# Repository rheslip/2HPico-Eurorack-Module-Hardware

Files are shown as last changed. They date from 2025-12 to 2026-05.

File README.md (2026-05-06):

# 2HPico-Eurorack-Module-Hardware
2HP and 4HP Eurorack modules based on Raspberry Pi RP2350 Pico 2

December 2025 - added Version 1.0 2HPico KiCad design files, BOM, Gerbers for main board and panel board and 3D printable panel.

Jan 28/2025 - added Version 1.0 2HPico DSP PCB design files and FR4 front panel design files and gerbers. 

Feb 16/2026 - JLCPCB assembly files are now verifed. Minor BOM changes to 2HPico DSP as a result of further testing.

April 13/2026 - added 4HPico DSP PCB files. PCB fabbed, tested and working with 1 jumper. 

May 6/2026 - updated 4HPico DSP PCB to V1.1 which corrects missing GND plane connection from middle to bottom of PCB. I have no plans to order these because V 1.0 is fine for me. Changes are minimal so not much risk in ordering V1.1.
Added .stl file for 3D printed panel. No plans to do a PCB panel at this point - I'm happy with the 3D printed panel.

2HPico, 2HPico DSP and 4HPico are complimentary designs intended for different uses:

The 2HPico has 1 or 2 CV inputs and 1 or 2 CV outputs depending on how its jumpered - see notes below. Its dual DAC CV output(s) can also be used for audio generated by the RP2350 processor. 2HPico can be used to process triggers, gates and CV inputs and can generate CV or audio out - its well suited for sequencers, LFOs,  oscillators etc.

2HPico DSP has an audio ADC and DAC to enable signal processing for audio effects like delays, reverbs, chorus etc. 

2HPico and 2HPico DSP use the same front panel and control panel PCBs. 

4HPico is basically the 2HPico DSP with stereo audio in and out and two dedicated CV inputs. Encoder with a 64x32 OLED display instead of pots for setting parameters. This is a single PCB design which requires a 3D printed panel or PCB panel.

See the repository https://github.com/rheslip/2HPico-Sketches for Pico Arduino sketches to run on the 2HPico.

See the repository https://github.com/rheslip/2HPico-DSP-Sketches for Pico Arduino sketches to run on the 2HPico DSP.

See the repository https://github.com/rheslip/4HPico-DSP-Sketches for Pico Arduino sketches to run on the 4HPico DSP.

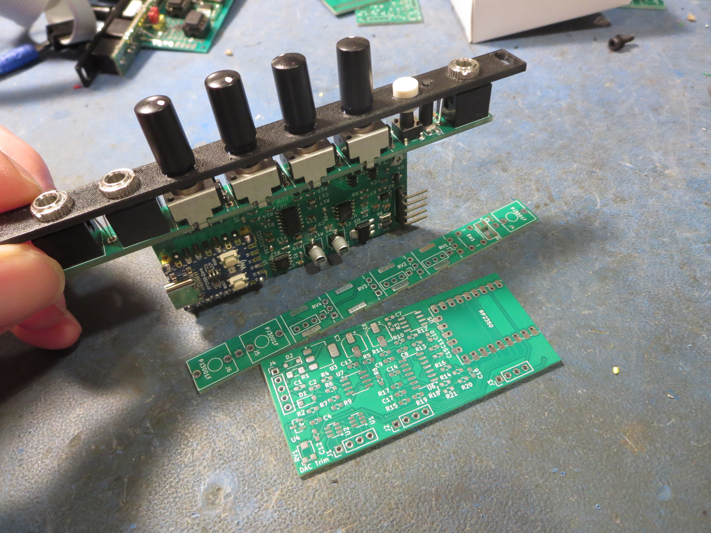
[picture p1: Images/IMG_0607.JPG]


***General notes on the designs***

Waveshare (and others) make small form factor RP2040 and RP2350 boards which make stuffing one into 2HP possible. The RP2350 has much better performance but for simple things like sequencers, ADSR, LFO etc the RP2040 should work OK. Core 0 runs the main processing loop for the UI and control,
core 1 runs the DSP and sends samples to the I2S driver. The code has an option for monitoring the performance of core 1 with a scope. If enabled you will see a pulse on GPIO 8 that indicates how much time core 1 is spending processing samples. If its high more than 100% of the time you will get audio dropouts - time to overclock or optimize your code some more!

The PT8211 16 bit stereo R2R DAC used on the 2HPico is very inexpensive and has proven so far to be quite accurate and consistent from one chip to another (provided they aren't defective - see caveats below). It has no internal antialiasing filters but it works down to DC so can be used as a CV out as well. U6 is a DC coupled antialiasing filter and it also amplifies the DAC output to +-5V eurorack levels.

The 2HPico DSP uses a PCM1808 24 bit stereo audio ADC and a PCM5102A 24 bit stereo audio DAC. The top panel jack is connected to both channels of the PCM1808 and one of the RP2350 ADCs. There is a "DC Input" jumper on the back of the board which shorts the input blocking cap so the top jack can be used for CV input. It adds an approximately 1.6V offset to the input signal so could cause high level audio inputs to clip. Its is recommended to leave the blocking cap in the circuit for audio processing applications.
As with the 2HPico, if the "DAC" solder jumper is shorted audio is sent to both of the lower front panel jacks. Both the PCM1808 and PCM5102A have internal antialiasing filters. Note that the 2HPico DSP can not generate CV outputs because the PCM5102A DAC must be AC coupled.

2HPico DSP build is pretty much the same as the 2HPico but you will be populating a couple of different parts - see the BOM.

***Panel PCB Build notes***

Solder the .1u cap and the RGB LED. Note pin 1 location is NOT the lead with the 45 cut on it - check the picture in the BOM. Hopefully you bought the right pinout! Note these are 5V parts but I haven't had any issues running them at 3.3v - and they are still way too bright!

Solder the jacks - note that the two bottom ones have the same GND via to save real estate

Solder the button. Glue the button cap on with a dab of superglue.

Solder the pots. You can clip the brackets near the bend to make soldering a bit easier but its not required. Make sure they are lined up vertically and horizontally before you solder the brackets to the pads. A Panavise is handy for this step.

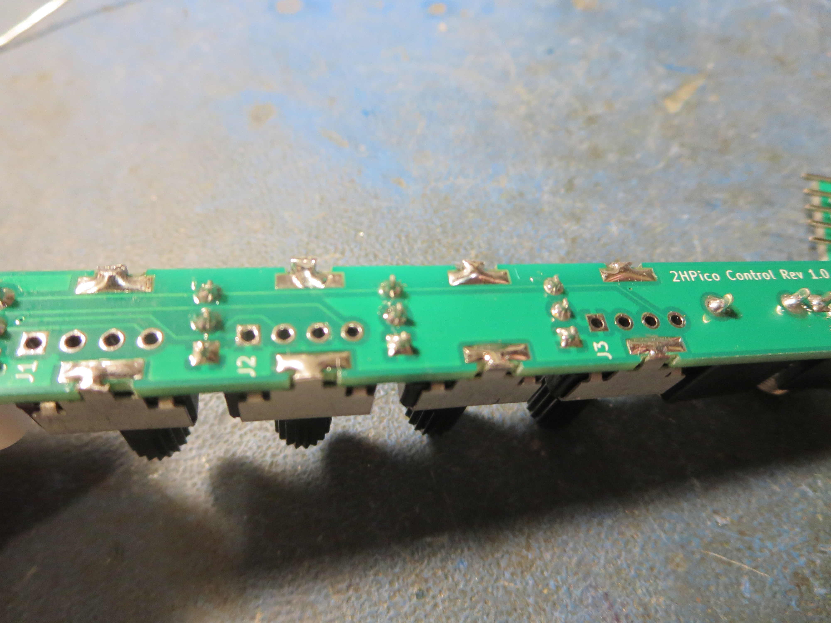
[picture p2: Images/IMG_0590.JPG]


***Main PCB Build Notes***

Solder all the 0603 Rs and Cs first

Solder diodes, R1, U3 regulator, U4 voltage reference and power connector J4. Hook it up to power and check that the 5V, -12V, +12V and -10v reference voltages are OK

Solder in all the chips, the larger caps and the trimpot RV1 (2HPico only).

The Waveshare RP2350 board cannot solder directly to the main PCB because it has components on the bottom side and must stand off a bit. You can solder .1" headers to it and solder the headers to the main PCB or solder .1" header pins in the corners and make the rest of the connections with short wires.

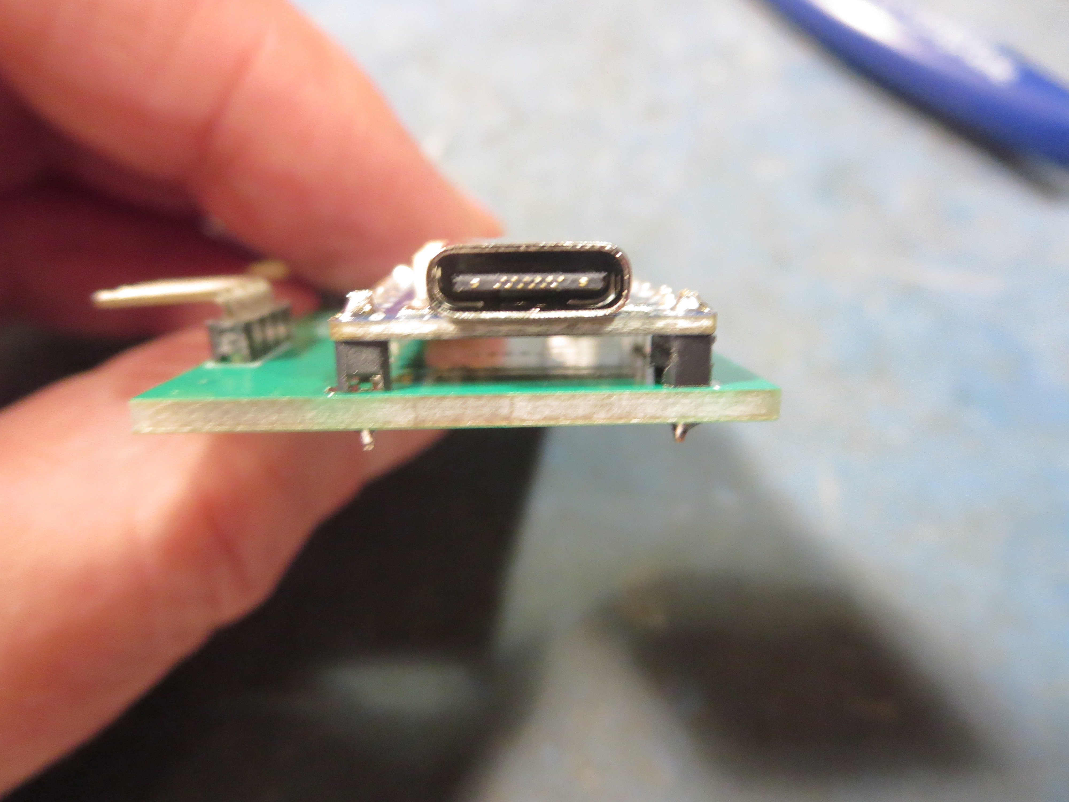
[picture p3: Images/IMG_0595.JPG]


Power up the PCB again and check that the 5V and 3.3V rails are OK.

Solder right angle connectors J1, J2 and J3. The shorter pins solder to the main PCB as shown.

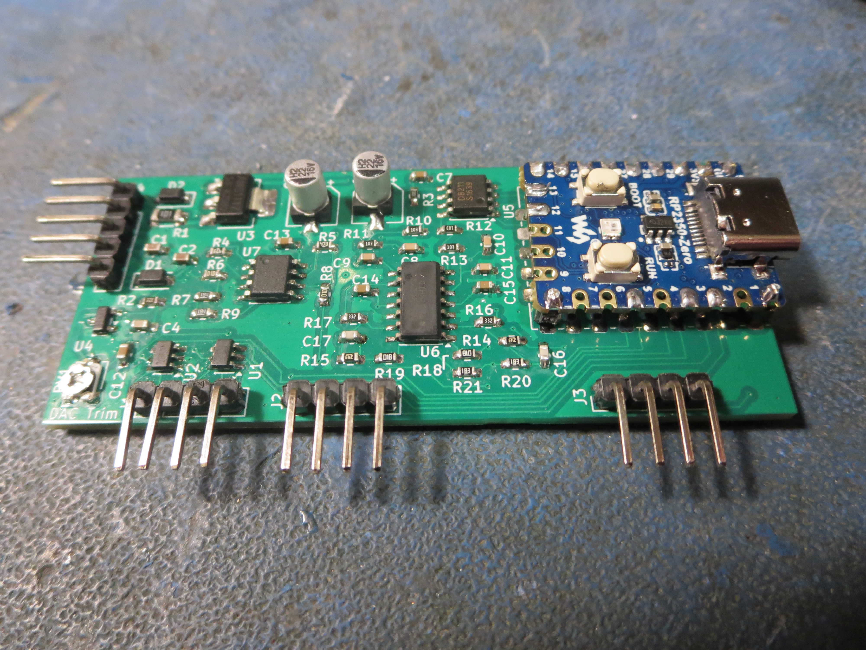
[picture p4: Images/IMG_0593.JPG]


Plug the long end of the right angle connectors into the panel PCB and solder.

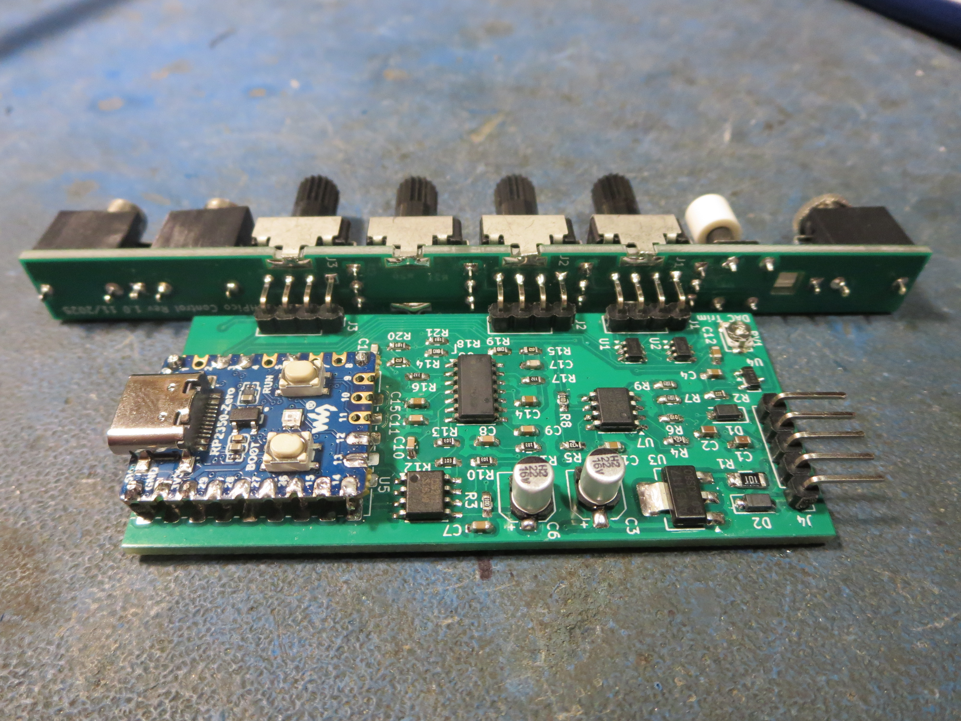
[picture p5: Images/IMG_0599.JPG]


Clip the pins on the bottom side of the main PCB so they don't interfere with adjacent modules - a 2HP module is supposed to be only 10.16mm wide.

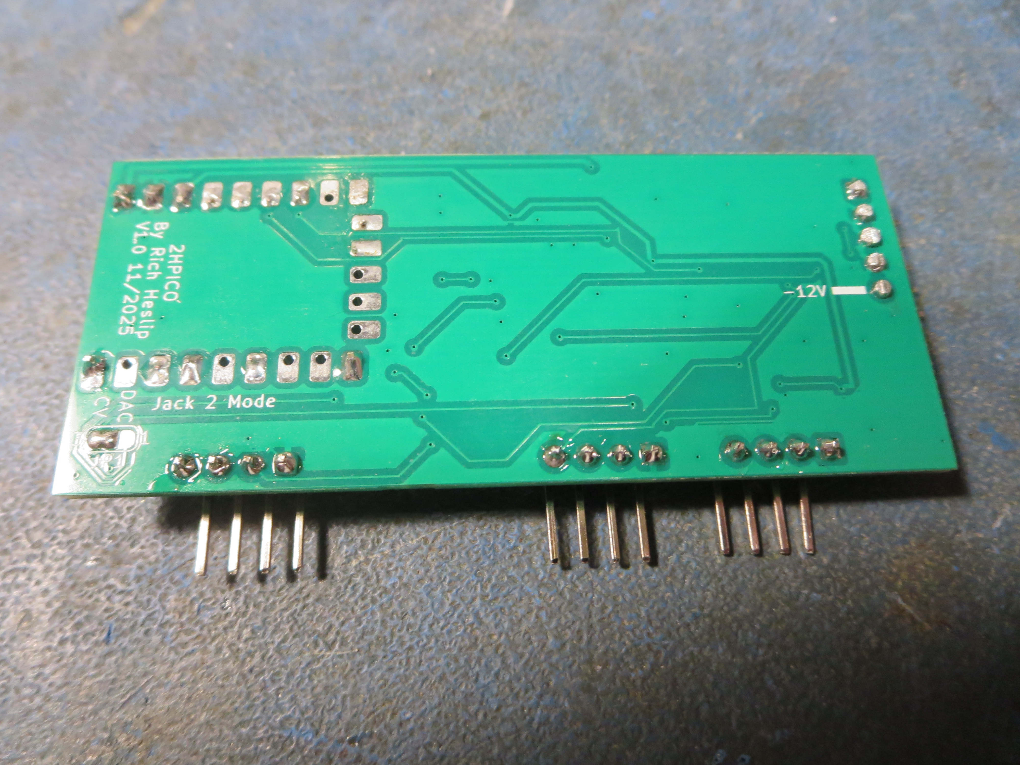
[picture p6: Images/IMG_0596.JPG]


Solder one of the jumper pads on the bottom to select jack 2 on the panel as either DAC right channel out or a second CV/Gate input. This depends on what the module is supposed to do.

The 2HPico DSP board has a "DC Input" solder jumper that should be shorted if you want to use the top jack as a CV input.

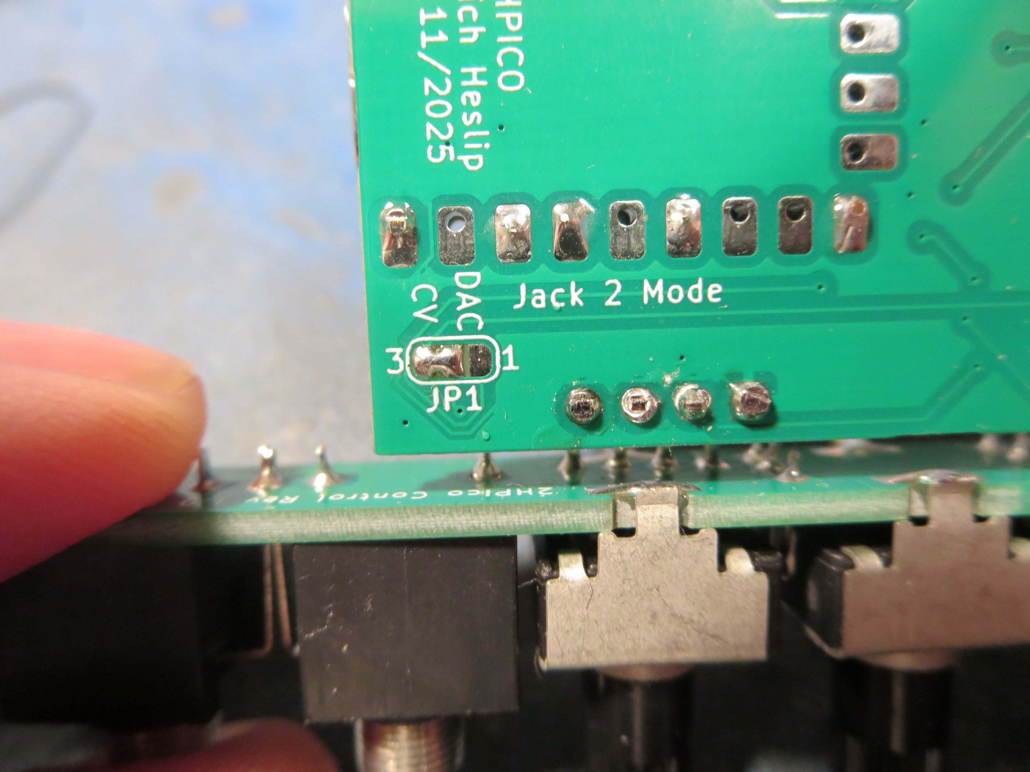
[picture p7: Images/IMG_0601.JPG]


It should be ready to go. You can load up the HWtest sketch and run it to check the pots, button, inputs and DAC functions.

***2HPico only - Trim the DAC output***

Load up the ADSR app or mod the HWtest sketch so the I2S code is sending the value 0 to the DACs. Measure the level at the output jacks or at U6 pins 1 and 14 and trim RV1 to get as close to 0V as possible. There will probably still be a few mV difference between the channels. 
Its set up for +-5V output corresponding to -32767 and 32767 DAC values respectively (output amp inverts the DAC signals). If you want higher output levels you can mod the output stage gain but keep in mind the offset and the lowpass filters also have to be recalculated.

***Notes on the PT8211 DAC chips for the 2HPico*** 

I bought 10 on Aliexpress and I got a couple of defective ones. Symptom was no output from either left or right DAC, just a low amplitude glitch at the opamp outputs U6 pins 1 and 14. I suggest you buy from a couple of different vendors and cross your fingers. Alternatively Sparkfun and PJRC sell PT8211 kits for a few dollars that include a PT8211 presumably from a reputable source.

***Notes on the PCM1808 and PCM5012A chips for the 2HPico DSP*** 

The PCM1808 ADC is 24 bit only wheras the PCM5102A works with either 16 bit or 24 bit I2S audio. Since they are on the same I2S interface they must both run the same format. I was not able to get 24 bit I2S working with Arduino Pico but it does work with 32 bit I2S. The additional overhead is minimal since the processor and DMA are 32 bits.

***Notes on the Panels***

STL file is included for a 3D printable panel which includes a collimator that sits over the RGB LED. I glued a short piece of transparent filament inside the collimator as a light pipe - for some reason commercial acrylic light pipes are stupidly expensive. The RGB LED is very bright even on 3.3v so I cut the level back in the code. I will probably design a silkscreened FR4 panel for it at some point.

FR4 front panel gerbers are also included. You will have to make a collimator from a small piece of plastic tubing to direct the RGB LED light to the hole in the panel. 



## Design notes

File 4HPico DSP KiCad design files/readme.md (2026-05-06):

**4HPico-Eurorack-Module-Hardware**

4HP Eurorack module based on Raspberry Pi RP2350 Pico 2

4HPico DSP is basically the 2HPico DSP with stereo audio in and out and two dedicated CV inputs. Encoder with a 64x32 OLED display instead of pots for setting parameters. This is a single PCB design which requires a 3D printed panel or PCB panel.

May 6/2026 - updated PCB to V1.1 which corrects missing GND plane connection from middle to bottom of PCB. 
not tested but changes are very minor

Added panel .stl file for 3D printing in /Panels. No plans to do a panel PCB at this point.

April 13/2026 - added 4HPico KiCad files V1.0. Boards fabbed and tested, working OK with jumper to connect middle and bottom GND planes.

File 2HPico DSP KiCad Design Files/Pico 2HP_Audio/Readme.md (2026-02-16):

Design files for the 2HPico DSP PCB

Feb 16/2026 - changed R1 to 47 ohms because 2HPico DSP consumes almost twice as much power as the 2HPico
changed R10 and R17 to 10k to reduce output amp gains - was getting some clipping at times.

The DSP version uses the same front panel board as the 2HPico but replaces the PT8211 DAC with a PCM5102A audio DAC and adds a PCM1808 audio ADC. This version is intended to be used for audio processing. 

The top input jack on the front panel can be used for audio input or CV input since its connected to both the audio ADC and the RP2350 ADC on GP26. A "DC Input" jumper has been added to the back of the PCB which shorts the DC blocking input capacitor so the top jack can be used as a CV input. 
Its recommended that this jumper be left open for audio use since it adds a ~ 1.6V offset to the input which could cause very high level audio inputs to clip in the opamp input stage. Also note that the scale of this CV input is different than the second one because the opamp gain was set for optimal audio levels.

The PCM1808 is 24 bit only and the PCM5102A is n the same I2S interface so they bot have to use the same data size. I could not get 24 bit PCM working with Pico Arduino but it does work with 32 bit PCM. The additonal overhead from 24 to 32 bit is minimal.

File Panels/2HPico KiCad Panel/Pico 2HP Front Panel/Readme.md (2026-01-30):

FR4 Panel for the 2HPico and 2HPico DSP

Kicad files for a PCB front panel. You will probably want to order this with black soldermask. Fits perfectly but I wish I'd make the silkscreen font a bit bigger :(

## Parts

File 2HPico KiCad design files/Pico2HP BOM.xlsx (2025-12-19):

Id | Designator | Footprint | Quantity | Designation | Supplier and ref | Link | Comments
1 | U7 | SOIC-8_3.9x4.9mm_P1.27mm | 1 | MCP6022 | Digikey,Mouser | https://www.digikey.ca/en/products/detail/microchip-technology/MCP6002T-I-SN/500878
2 | R2 | R_0603_1608Metric_Pad0.98x0.95mm_HandSolder | 1 | 2.2k
3 | R14,R15 | R_0603_1608Metric_Pad0.98x0.95mm_HandSolder | 2 | 24k 1%
4 | J2,J1,J3 | PinHeader_1x04_P2.54mm_R/A | 3 | Conn_01x04_Pin | Digikey,Aliexpress | see pic below | Connects PCB to panel - 90 degree mount. ~ 3mm solder side to main board, ~ 5mm to panel. See below
5 | C6 | CP_Elec_5x5.9 | 1 | 47u |  |  | value not critical 22-100u, 6V rating or higher
6 | U6 | SOIC-14_3.9x8.7mm_P1.27mm | 1 | TL074 |  | https://www.digikey.ca/en/products/detail/texas-instruments/TL074CDR/276926
7 | R19,R18 | R_0603_1608Metric_Pad0.98x0.95mm_HandSolder | 2 | 1k 1%
8 | C15,C12,C13,C7,C14,C4 | C_0603_1608Metric_Pad1.08x0.95mm_HandSolder | 6 | .1u
9 | R16,R17 | R_0603_1608Metric_Pad0.98x0.95mm_HandSolder | 2 | 3.3k 1%
10 | R21,R20 | R_0603_1608Metric_Pad0.98x0.95mm_HandSolder | 2 | 18k 1%
11 | R13,R10,R12,R11 | R_0603_1608Metric_Pad0.98x0.95mm_HandSolder | 4 | 10k
12 | C16,C17 | C_0603_1608Metric_Pad1.08x0.95mm_HandSolder | 2 | 220p
13 | C11,C8 | C_0603_1608Metric_Pad1.08x0.95mm_HandSolder | 2 | 470p
14 | R1 | R_1206_3216Metric_Pad1.30x1.75mm_HandSolder | 1 | 100R
15 | R4,R5 | R_0603_1608Metric_Pad0.98x0.95mm_HandSolder | 2 | 47k 1%
16 | C3 | CP_Elec_5x5.9 | 1 | 22u 16V
17 | RV1 | Potentiometer_Bourns_TC33X 3mm | 1 | 5k Zero Trim |  |  | pads will fit most small SMT trimpots. 10k will work too
18 | U4 | SOT-23 | 1 | LM4040DBZ-10 |  | https://www.digikey.ca/en/products/detail/texas-instruments/LM4040DIM3-10-0-NOPB/305141
19 | R9,R7 | R_0603_1608Metric_Pad0.98x0.95mm_HandSolder | 2 | 180k 1%
20 | U1,U2 | SOT-23-6 | 2 | 74LVC1G3157 |  | https://www.digikey.ca/en/products/detail/texas-instruments/SN74LVC1G3157DCKR/562895
21 | C2,C1 | C_0603_1608Metric_Pad1.08x0.95mm_HandSolder | 2 | 10u 16V |  |  | 0603 ceramic
22 | U5 | SOIC-8_3.9x4.9mm_P1.27mm | 1 | PT8211 DAC | Aliexpress *** | lots of suppliers - roll the dice | Don't buy semis from Aliexpress unless you have to -fake and defective parts are common
23 | C10,C9 | C_0603_1608Metric_Pad1.08x0.95mm_HandSolder | 2 | 1000p
24 | D2,D1 | D_SOD-123 | 2 | 1N5819WS |  | https://www.digikey.ca/en/products/detail/shenzhen-slkormicro-semicon-co-ltd/1N5819W/26112808
25 | J4 | PinHeader_1x05_P2.54mm_R/A | 1 | Conn_01x05_Pin |  |  | Power connector - 90 degree mount. Same as J1-J3 but 5 contacts. Slightly longer pins will be a bit more secure connection
26 | R8,R6 | R_0603_1608Metric_Pad0.98x0.95mm_HandSolder | 2 | 100k 1%
27 | R3 | R_0603_1608Metric_Pad0.98x0.95mm_HandSolder | 1 | 10R
28 | RZ1 | RP2350-Waveshare - get the pinout below | 1 | RP2350 | Amazon or AliExpress | https://www.amazon.ca/RP2350-Zero-Development-Dual-Architecture-Microcontroller-Multi-Function/dp/B0F2YD8JDR
29 | U3 | SOT-223-3_TabPin2 | 1 | AMS1117-5.0 |  | https://www.digikey.ca/en/products/detail/evvo/AMS1117-5-0/24370130 | 5V regulator - most 1117 type regulators have the same pinout
30 |  | PinHeader_1x09_P2.54mm | 2 |  | Digikey, AliExpress | buy the long ones at cut to length | Mounts RP2350 module to PCB - could just use short wires
31 |  | PinHeader_1x05_P2.54mm | 1 |  | Digikey, AliExpress |  | Mounts RP2350 module to PCB - could just use short wires
 |  |  |  | *** PT8211 - I bought 10 on AliExpress and had a couple of defective ones. Buy from a couple of different vendors - they are cheap

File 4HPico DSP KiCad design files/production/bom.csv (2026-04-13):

Designator | Footprint | Quantity | Value | LCSC Part #
C1, C10, C19, C2, C20, C6, C8 | 0603 | 7 | 10u
C11, C18, C25, C26 | 0603 | 4 | 1u
C12, C13, C14, C15, C16, C23, C24, C4, C7, C9 | 0603 | 10 | .1u
C17, C5 | 0603 | 2 | 18p
C21, C22 | 0603 | 2 | 2.2u
C3 | CP_Elec_5x5.9 | 1 | 22u
D1, D2 | D_SOD-123 | 2 | 1N5819WS
J1, J2, J3, J4, J5, J6 | AudioJack_3.5mm | 6 | PJ3001F
J7 | PinHeader_2x05_P2.54mm_Vertical | 1 | Conn_02x05_Odd_Even
J8 | PinHeader_1x04_P2.54mm_Vertical | 1 | Conn_01x04_Pin
JP1, JP2 | SolderJumper-2_P1.3mm_Open_RoundedPad1.0x1.5mm | 2 | DC INPUT
L1, L2 | 0603 | 2 | 33uH
R1, R22 | 1206 | 2 | 100R
R10, R17 | 0603 | 2 | 10k
R11, R15 | 0603 | 2 | 39k
R12, R19 | 0603 | 2 | 1k
R13, R14 | 0603 | 2 | 20k
R16, R21, R6, R8 | 0603 | 4 | 100k
R18, R20 | 0603 | 2 | 120k
R2 | 0603 | 1 | 2.2k
R3 | 0603 | 1 | 33
R4, R5 | 0603 | 2 | 47k
R7, R9 | 0603 | 2 | 180k
RZ1 | RP2350-Waveshare | 1 | RP2350-WaveShare
SW1 | RotaryEncoder_Alps_EC11E-Switch_Vertical_H20mm_topsolder | 1 | RotaryEncoder_Switch
U3 | SOT-223-3_TabPin2 | 1 | AMS1117-5.0
U4 | SOT-23 | 1 | LM4040DBZ-10
U5 | SOIC-8_3.9x4.9mm_P1.27mm | 1 | TL072
U6 | TSSOP-20_4.4x6.5mm_P0.65mm | 1 | PCM5102A
U7, U9 | SOIC-8_3.9x4.9mm_P1.27mm | 2 | MCP6022
U8 | TSSOP-14_4.4x5mm_P0.65mm | 1 | PCM1808PWR

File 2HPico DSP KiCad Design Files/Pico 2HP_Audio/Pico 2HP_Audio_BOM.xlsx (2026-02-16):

Reference | Qty | Value | Footprint | Link | Comments | Datasheet
C1,C2,C6,C8,C10,C19,C20 | 7 | 10u 16v | 0603 |  |  | ~
C3 | 1 | 22u 16v | SMD 5x5.9 |  | most 22u SMT caps will fit on the pads | ~
C4,C7,C9,C12,C13,C14,C15,C16,C23,C24 | 10 | .1u | 0603 |  |  | ~
C5,C17 | 2 | 18p | 0603 |  |  | ~
C11,C18 | 2 | 1u | 0603 |  |  | ~
C21,C22 | 2 | 2.2u | 0603 |  |  | ~
D1,D2 | 2 | 1N5819WS | SOD-123 |  |  | https://datasheet.lcsc.com/lcsc/2204281430_Guangdong-Hottech-1N5819WS_C191023.pdf
J1,J2,J3 | 3 | Conn_01x04_Pin | R/A 2.54mm |  | board interconnect - se below | ~
J4 | 1 | R/A 2.54mm | R/A 2.54mm |  | power input - see pic below | ~
JP1 | 1 | JACK 2 SELECT | SolderJumper |  | selects middle jack audio out or CV in | ~
JP2 | 1 | DC INPUT | SolderJumper |  | solder for CV input on top jack | ~
L1,L2 | 2 | 33uH | 0603 |  |  | ~
R1 | 1 | 47R | 1206 |  |  | ~
R2 | 1 | 2.2k | 0603 |  |  | ~
R3 | 1 | 33R | 0603 |  |  | ~
R4 | 1 | 20k | 0603 |  |  | ~
R5 | 1 | 47k | 0603 |  |  | ~
R6,R8 | 2 | 100k | 0603 |  |  | ~
R7 | 1 | 120k | 0603 |  |  | ~
R9 | 1 | 180k | 0603 |  |  | ~
R10,R17 | 2 | 10k | 0603 |  |  | ~
R11,R15 | 2 | 39k | 0603 |  |  | ~
R12,R19 | 2 | 1k | 0603 |  |  | ~
RZ1 | 1 | RP2350-WaveShare | RP2350-Waveshare | https://www.amazon.ca/RP2350-Zero-Development-Dual-Architecture-Microcontroller-Multi-Function/dp/B0F2YD8JDR | see pic below for pinout
U1,U2 | 2 | 74LVC1G3157 | SOT-23-6 | https://www.digikey.ca/en/products/detail/texas-instruments/SN74LVC1G3157DCKR/562895 |  | http://www.ti.com/lit/sg/scyt129e/scyt129e.pdf
U3 | 1 | AMS1117-5.0 | SOT-223-3_TabPin2 | https://www.digikey.ca/en/products/detail/evvo/AMS1117-5-0/24370130 |  | http://www.advanced-monolithic.com/pdf/ds1117.pdf
U4 | 1 | LM4040DBZ-10 | SOT-23 | https://www.digikey.ca/en/products/detail/texas-instruments/LM4040DIM3-10-0-NOPB/305141 |  | http://www.ti.com/lit/ds/symlink/lm4040-n.pdf
U5 | 1 | TL072 | SOIC-8_3.9x4.9mm | https://www.digikey.ca/en/products/detail/texas-instruments/TL072CDR/276925 |  | http://www.ti.com/lit/ds/symlink/tl071.pdf
U6 | 1 | PCM5102A | TSSOP-20_4.4x6.5mm | https://www.digikey.ca/en/products/detail/texas-instruments/PCM5102APWR/3727211 |  | http://www.ti.com/lit/ds/symlink/pcm5102.pdf
U7 | 1 | MCP6022 | SOIC-8_3.9x4.9mm | https://www.digikey.ca/en/products/detail/microchip-technology/MCP6002T-I-SN/500878 |  | http://ww1.microchip.com/downloads/en/devicedoc/20001685e.pdf
U8 | 1 | PCM1808PWR | TSSOP-14_4.4x5mm | https://www.digikey.ca/en/products/detail/texas-instruments/PCM1808PWR/1573355

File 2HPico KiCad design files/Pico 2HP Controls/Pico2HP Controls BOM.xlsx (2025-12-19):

Id | Designator | Footprint | Quantity | Designation | Supplier and ref | Link | Comments
1 | D1 | LED_OPSCO_SK6812_MINI-E_3228SMD Reverse Mount | 1 | SK6812E-MINI | AliExpress | https://www.aliexpress.com/item/1005005193716172.html | check the pinout before you buy!
2 | J5,J4,J6 | PJ-301M AudioJack_3.5mm | 3 | PJ3001F | AliExpress | https://www.aliexpress.com/item/32919567094.html | standard eurorack jacks
3 | RV4,RV2,RV3,RV1 | Potentiometer_RV09_10HP | 4 | R_Potentiometer_US | AliExpress | https://www.aliexpress.com/item/1005003276146441.html | 10k to 100k is fine - could also use Song Huei style plastic pots with pointer on shaft
4 | C1 | C_0603_1608Metric_Pad1.08x0.95mm_HandSolder | 1 | .1u
5 | SW1 | SW_PUSH_6mm (13mm shaft) | 1 | SW_SPST | AliExpress | https://www.aliexpress.com/item/1005003115135192.html | 10-15mm shaft will work
6 |  | Switch Cap |  |  | AliExpress | https://www.aliexpress.com/item/32823372863.html | glue them on
7 |  | Knobs to fit pots | 4 |  | AliExpress | https://www.aliexpress.com/item/33009959086.html | ***** do NOT use metal pots - the frame will short the board connectors

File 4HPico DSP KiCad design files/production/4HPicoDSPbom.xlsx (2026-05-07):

Designator | Footprint | Quantity | Value | LCSC Part # | Comments | Link
C1, C10, C19, C2, C20, C6, C8 | 603 | 7 | 10u 16v
C11, C18, C25, C26 | 603 | 4 | 1u 16v
C12, C13, C14, C15, C16, C23, C24, C4, C7, C9 | 603 | 10 | .1u
C17, C5 | 603 | 2 | 18p
C21, C22 | 603 | 2 | 2.2u
C3 | CP_Elec_5x5.9 | 1 | 22u 16V
D1, D2 | D_SOD-123 | 2 | 1N5819WS |  |  | https://www.digikey.ca/en/products/detail/shenzhen-slkormicro-semicon-co-ltd/1N5819W/26112808
J1, J2, J3, J4, J5, J6 | AudioJack_3.5mm | 6 | PJ3001F
J7 | PinHeader_2x05_P2.54mm_Vertical | 1 | Conn_02x05_Odd_Even |  | eurorack 2x5 power header
J8 |  |  |  |  | OLED mounting holes
JP1, JP2 | SolderJumper-2_P1.3mm_Open_RoundedPad1.0x1.5mm | 2 |  |  | selects AC or DC input on J3, J4
L1, L2 | 603 | 2 | 33uH
R1, R22 | 1206 | 2 | 100R
R10, R17 | 603 | 2 | 10k
R11, R15 | 603 | 2 | 39k
R12, R19 | 603 | 2 | 1k
R13, R14 | 603 | 2 | 20k
R16, R21, R6, R8 | 603 | 4 | 100k
R18, R20 | 603 | 2 | 120k
R2 | 603 | 1 | 2.2k
R3 | 603 | 1 | 33
R4, R5 | 603 | 2 | 47k
R7, R9 | 603 | 2 | 180k
RZ1 | RP2350-Waveshare | 1 | RP2350-WaveShare |  | Amazon or AliExpress | https://www.amazon.ca/RP2350-Zero-Development-Dual-Architecture-Microcontroller-Multi-Function/dp/B0F2YD8JDR
SW1 | RotaryEncoder_Alps_EC11E-Switch_Vertical_H20mm_topsolder | 1 | RotaryEncoder_Switch |  | EC11 style | https://www.aliexpress.com/item/1005001423308166.html
U3 | SOT-223-3_TabPin2 | 1 | AMS1117-5.0 |  |  | https://www.digikey.ca/en/products/detail/evvo/AMS1117-5-0/24370130
U4 | SOT-23 | 1 | LM4040DBZ-10 |  |  | https://www.digikey.ca/en/products/detail/texas-instruments/LM4040DIM3-10-0-NOPB/305141
U5 | SOIC-8_3.9x4.9mm_P1.27mm | 1 | TL072 |  |  | https://www.digikey.ca/en/products/detail/texas-instruments/TL072CDR/276925
U6 | TSSOP-20_4.4x6.5mm_P0.65mm | 1 | PCM5102A |  |  | https://www.digikey.ca/en/products/detail/texas-instruments/PCM5102APWR/3727211
U7, U9 | SOIC-8_3.9x4.9mm_P1.27mm | 2 | MCP6022 |  |  | https://www.digikey.ca/en/products/detail/microchip-technology/MCP6002T-I-SN/500878
U8 | TSSOP-14_4.4x5mm_P0.65mm | 1 | PCM1808PWR |  |  | https://www.digikey.ca/en/products/detail/texas-instruments/PCM1808PWR/1573355
OLED Display .49" 64x32 Pixel SSD1306 | J8 | 1 |  |  | Amazon or AliExpress | https://www.aliexpress.com/item/1005006866137846.html
Front Panel |  |  |  |  | 3D printed - STL file in the github archive

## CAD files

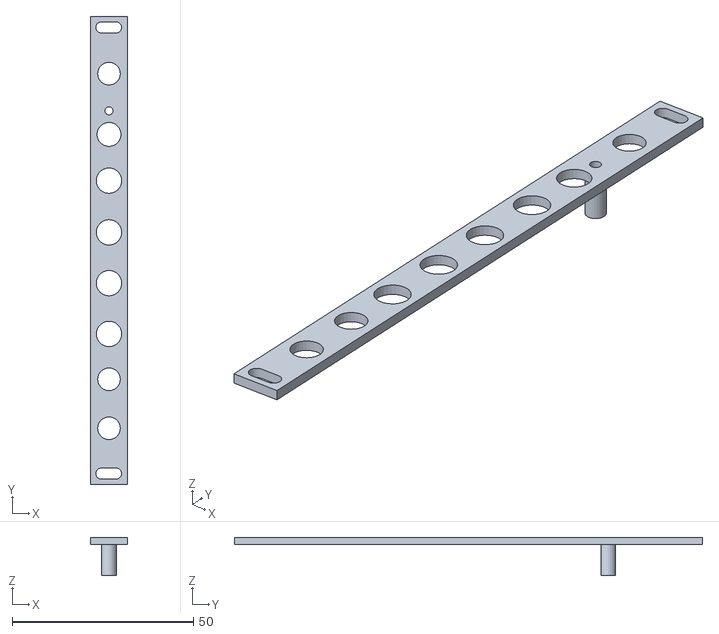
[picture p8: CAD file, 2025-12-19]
Panels/2HPico STL file for 3d Printing/2HPico Panel.stl
10.2 x 129.0 x 10.5

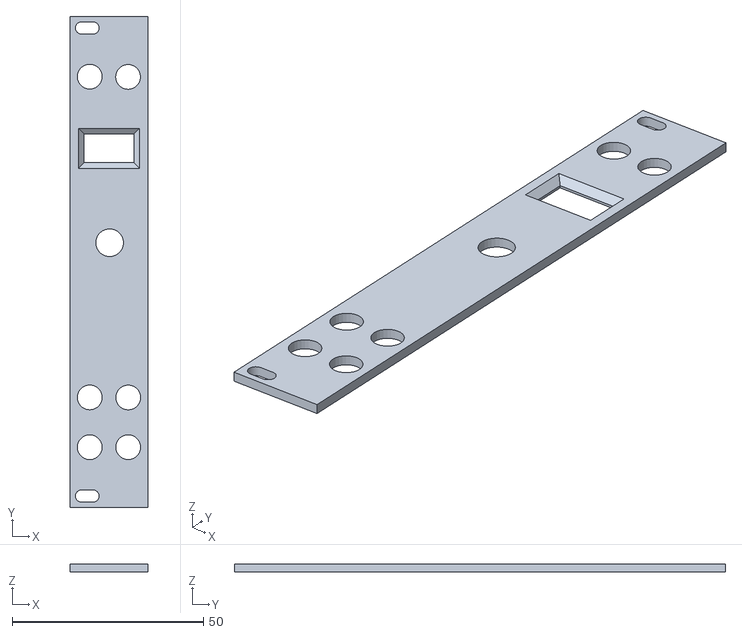
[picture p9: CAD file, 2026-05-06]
Panels/4HPico Panel for 3D Printing/4HPico Panel.stl
20.4 x 128.5 x 2.00

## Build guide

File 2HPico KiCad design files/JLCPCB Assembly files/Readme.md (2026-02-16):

JLCPCB Assembly files for the 2HPico DSP courtesy of Blake @abandonedireland on Youtube

Feb 16/2026 - Blake has received and tested his boards and veriefied that they work OK.

JLCPCB can do SMT assembly of PCBs at relatively low cost. Briefly, the procedure is:

Upload the Gerber files for the PCB

Select PCB assembly and go thru the prompts. It will ask you for a BOM file and a CPL (placement) file - upload these.

It will show you a 3d preview of the assembled board to verify, a detailed cost breakdown of the BOM and the price for the assembled boards.

Note that JLCPCB has a minimum order of 5 boards but the price is very reasonable. I got a quote of $67 USD for 5 assembled boards plus shipping. You will also need to order the front panel PCB and the controls PCBs which will be an additional $10 or so. New JLCPCB customers often get coupons for discounts.

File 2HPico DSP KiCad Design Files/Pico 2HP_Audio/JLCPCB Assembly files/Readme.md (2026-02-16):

JLCPCB Assembly files for the 2HPico DSP courtesy of Blake @abandonedireland on Youtube

Feb 16/2026 Blake has received and tested his boards - they work OK after R1 change. 
 
A couple of small BOM changes as a result of testing:
R1 reduced from 100 ohms to 47 ohms because 2HPico DSP draws more current than 2HPico
R10, R17 increased from 5.6k to 10k to avoid clipping in output audio stage

JLCPCB can do SMT assembly of PCBs at relatively low cost. Briefly, the procedure is:

Upload the Gerber files for the PCB

Select PCB assembly and go thru the prompts. It will ask you for a BOM file and a CPL (placement) file - upload these.

It will show you a 3d preview of the assembled board to verify, a detailed cost breakdown of the BOM and the price for the assembled boards.

Note that JLCPCB has a minimum order of 5 boards but the price is very reasonable. I got a quote of $67 USD for 5 assembled boards plus shipping. You will also need to order the front panel PCB and the controls PCBs which will be an additional $10 or so. New JLCPCB customers often get coupons for discounts.

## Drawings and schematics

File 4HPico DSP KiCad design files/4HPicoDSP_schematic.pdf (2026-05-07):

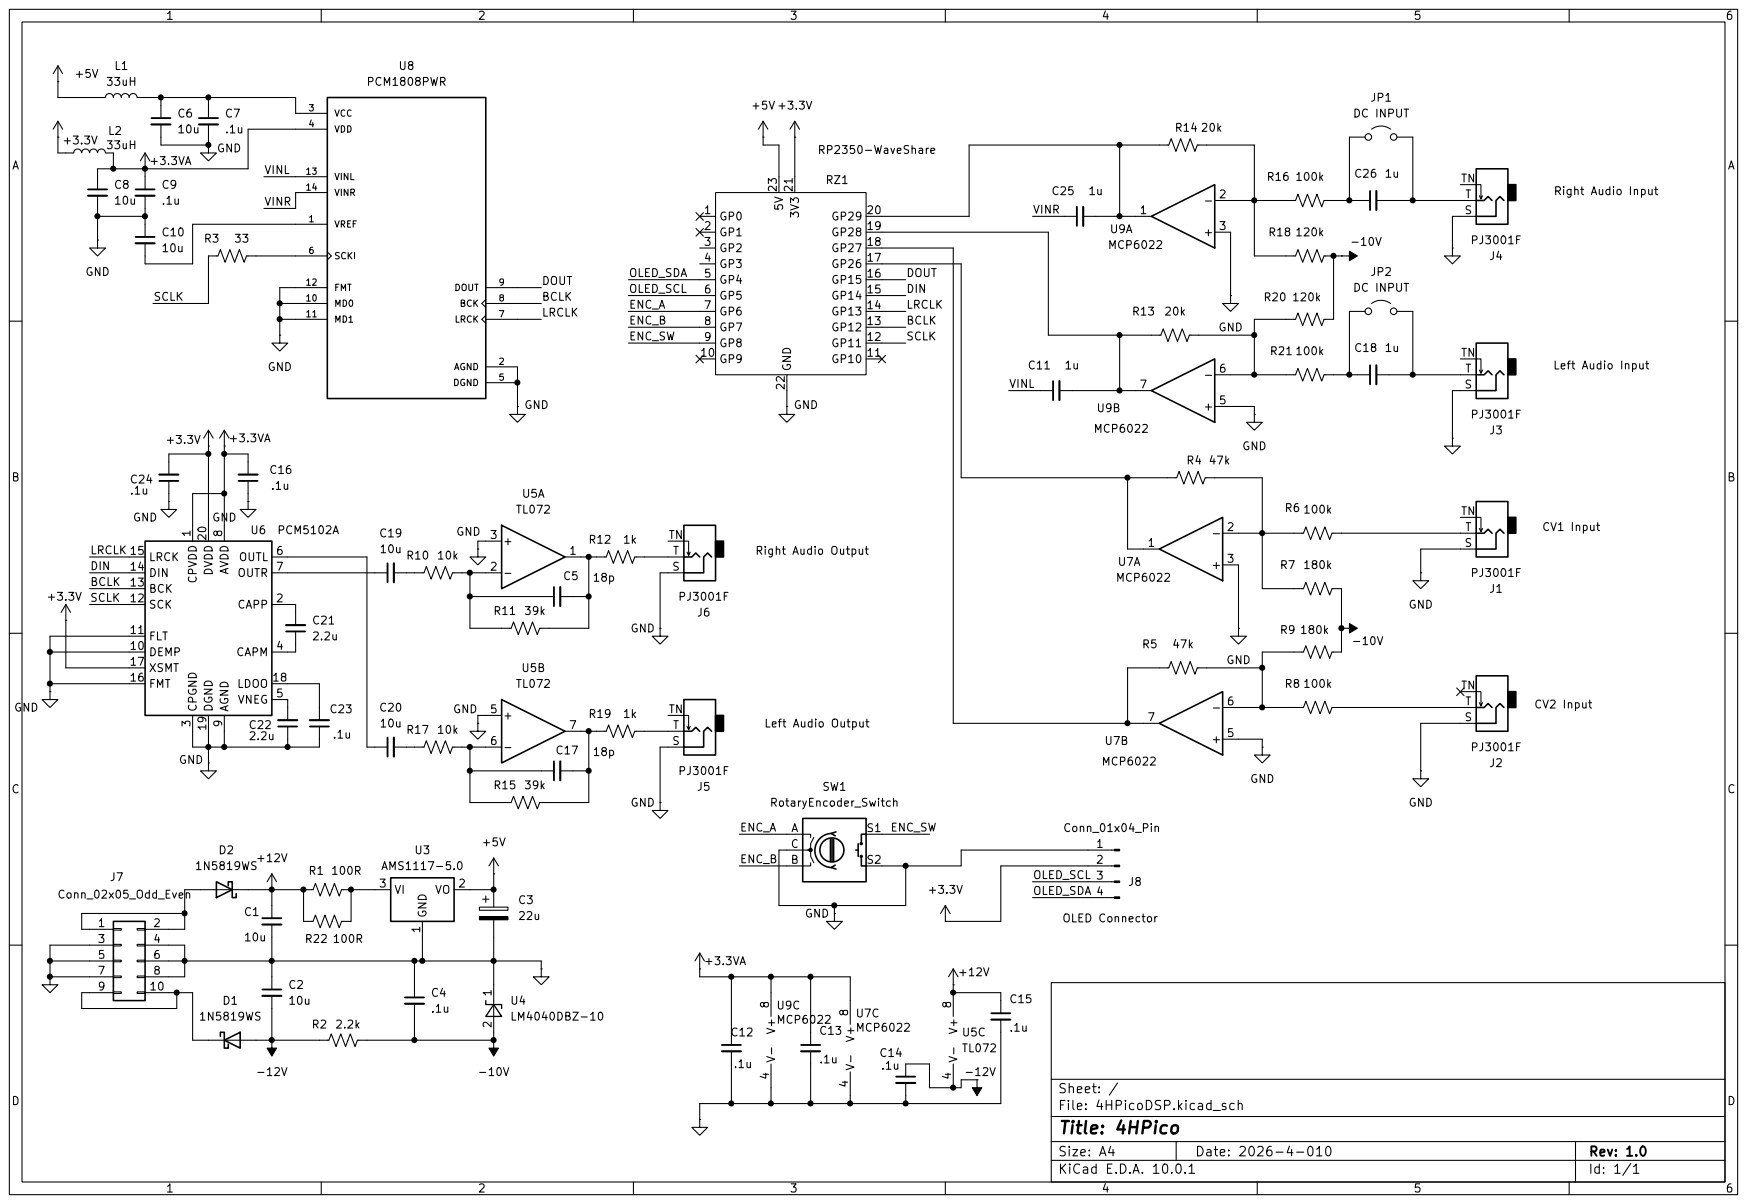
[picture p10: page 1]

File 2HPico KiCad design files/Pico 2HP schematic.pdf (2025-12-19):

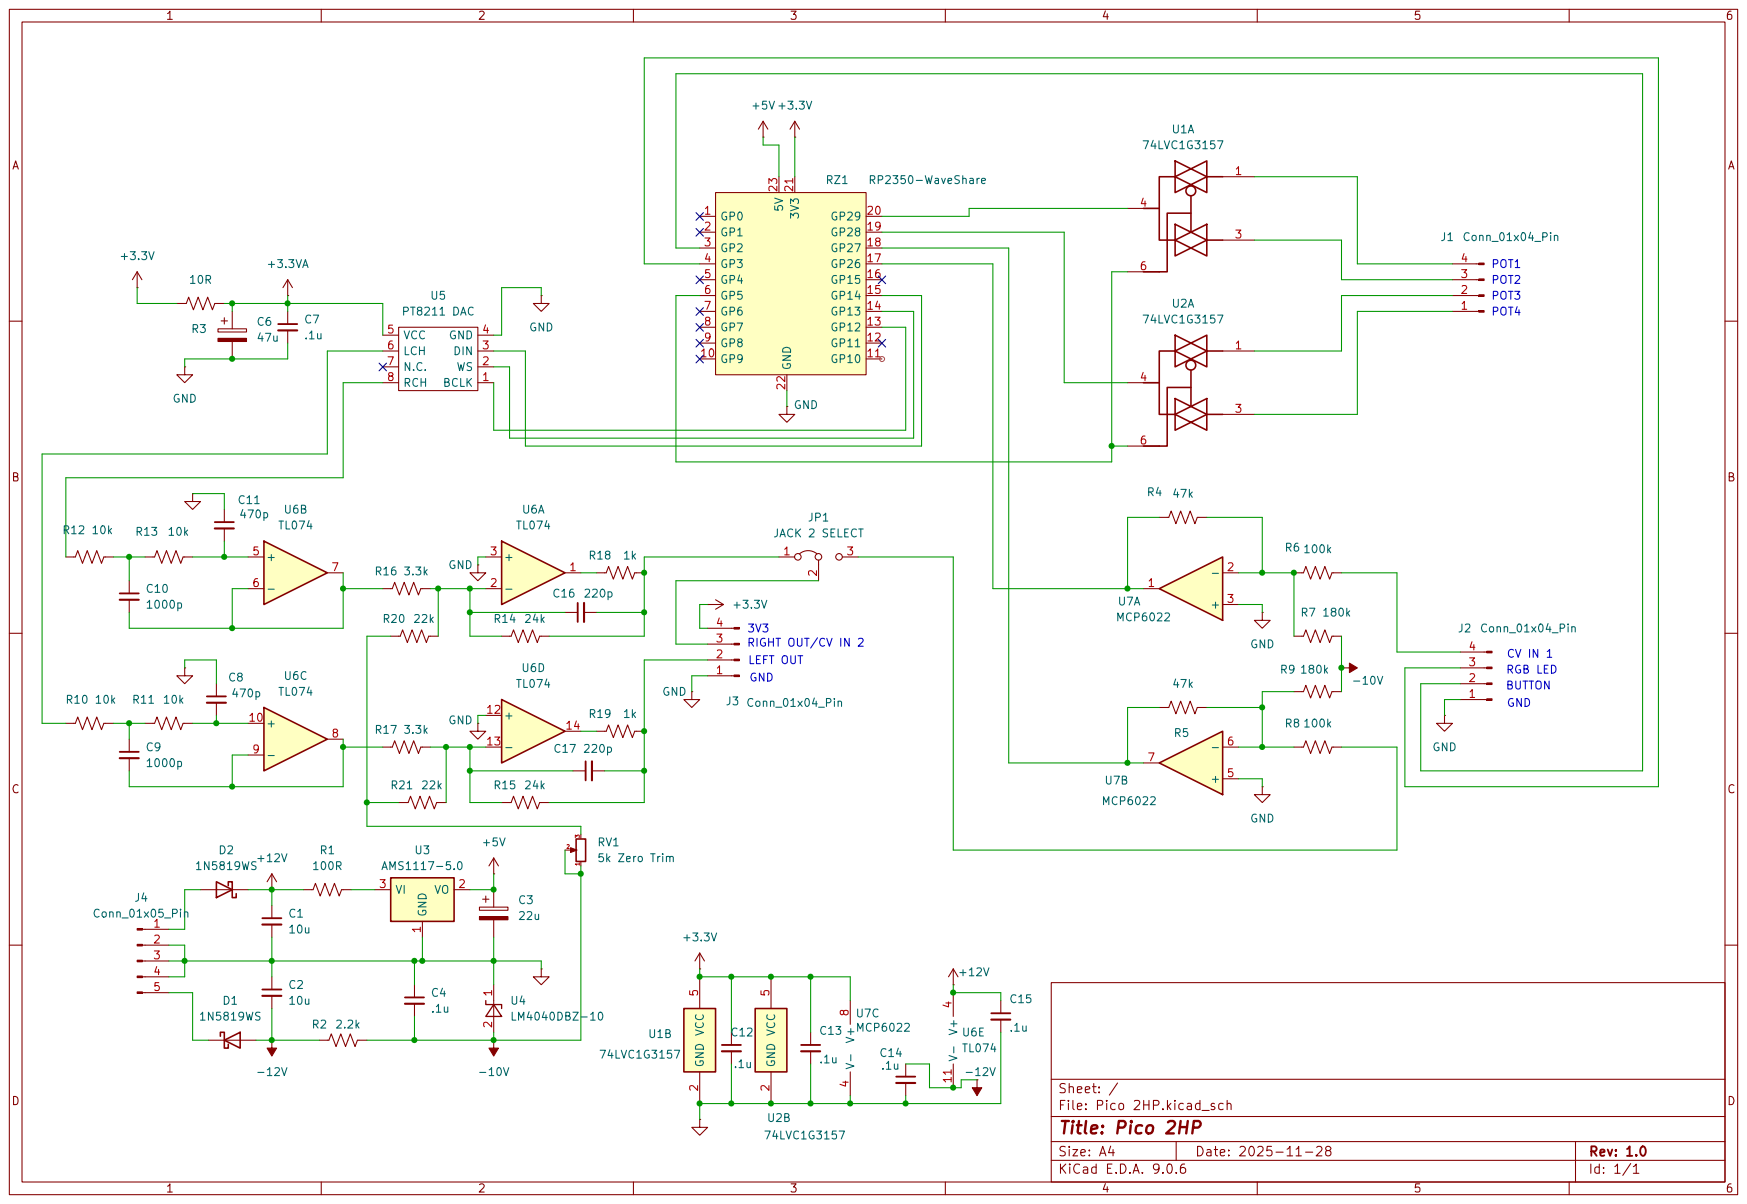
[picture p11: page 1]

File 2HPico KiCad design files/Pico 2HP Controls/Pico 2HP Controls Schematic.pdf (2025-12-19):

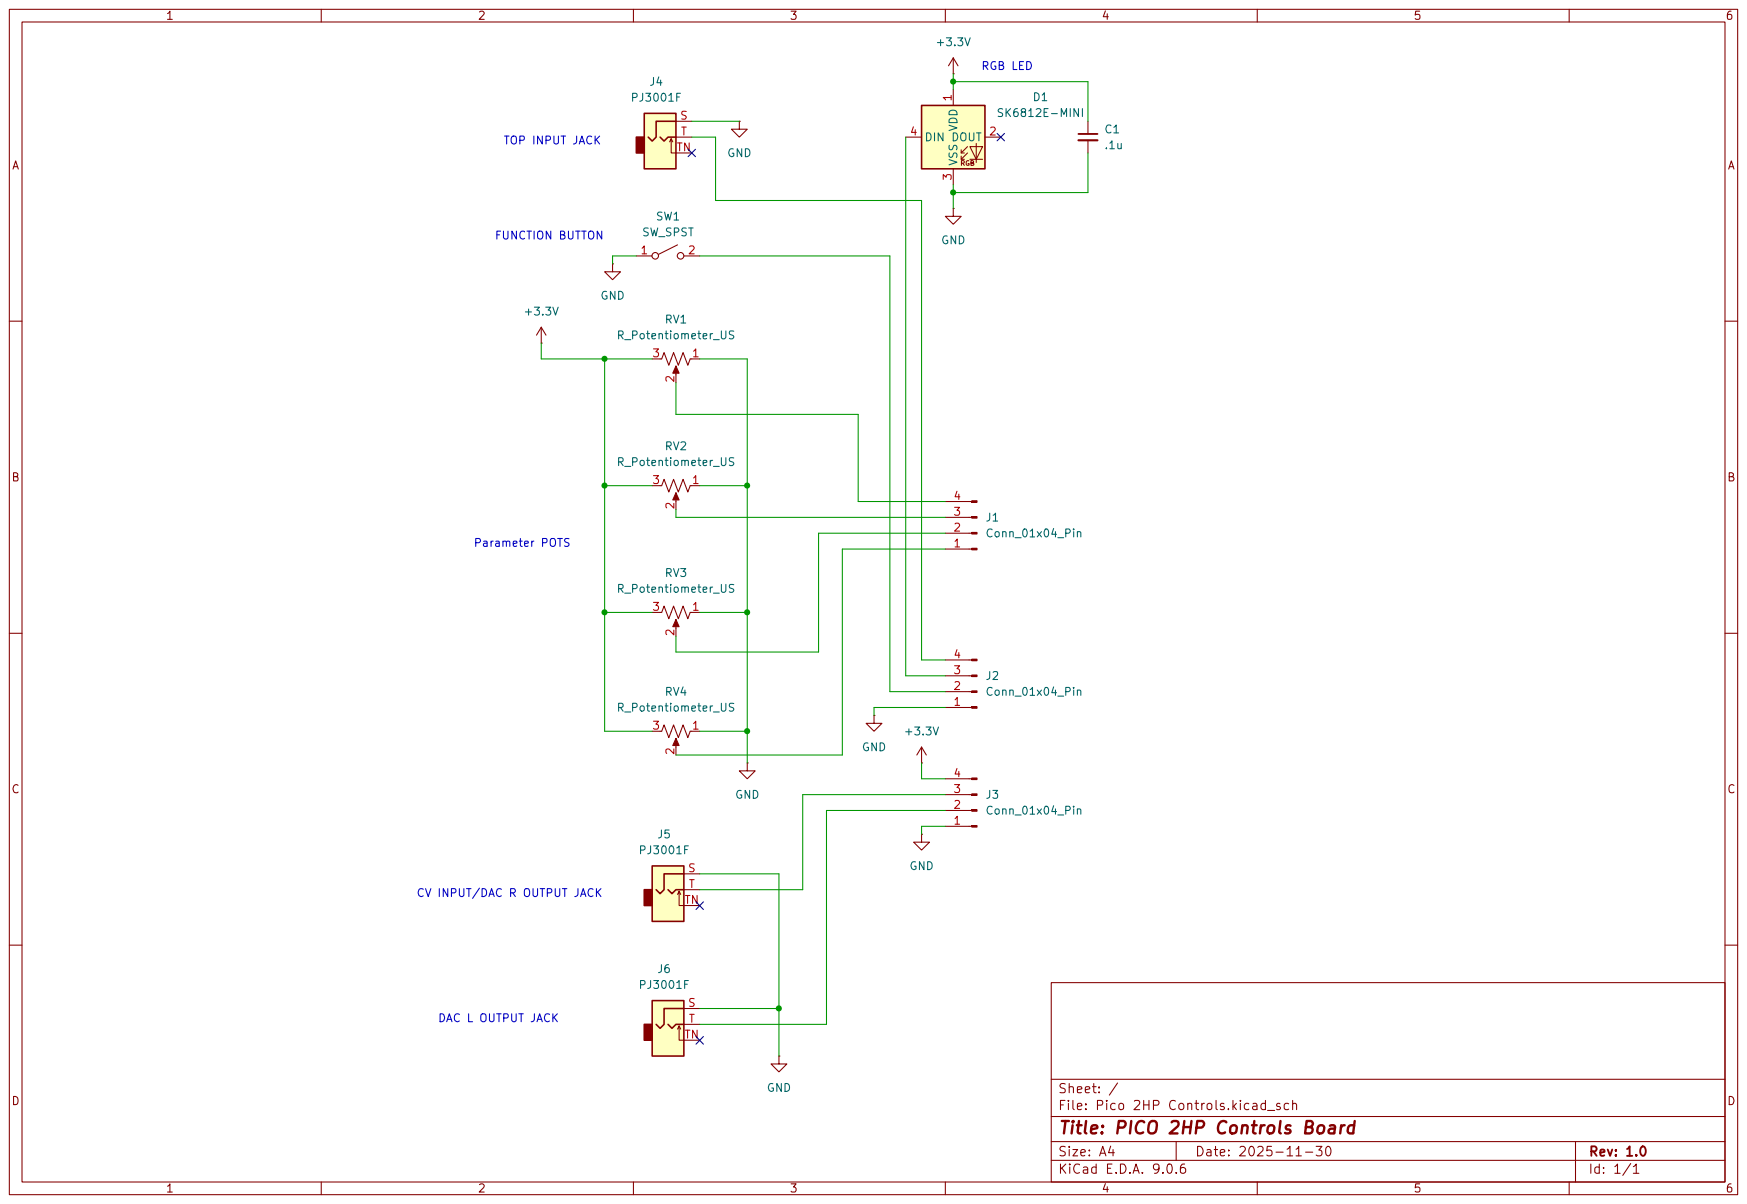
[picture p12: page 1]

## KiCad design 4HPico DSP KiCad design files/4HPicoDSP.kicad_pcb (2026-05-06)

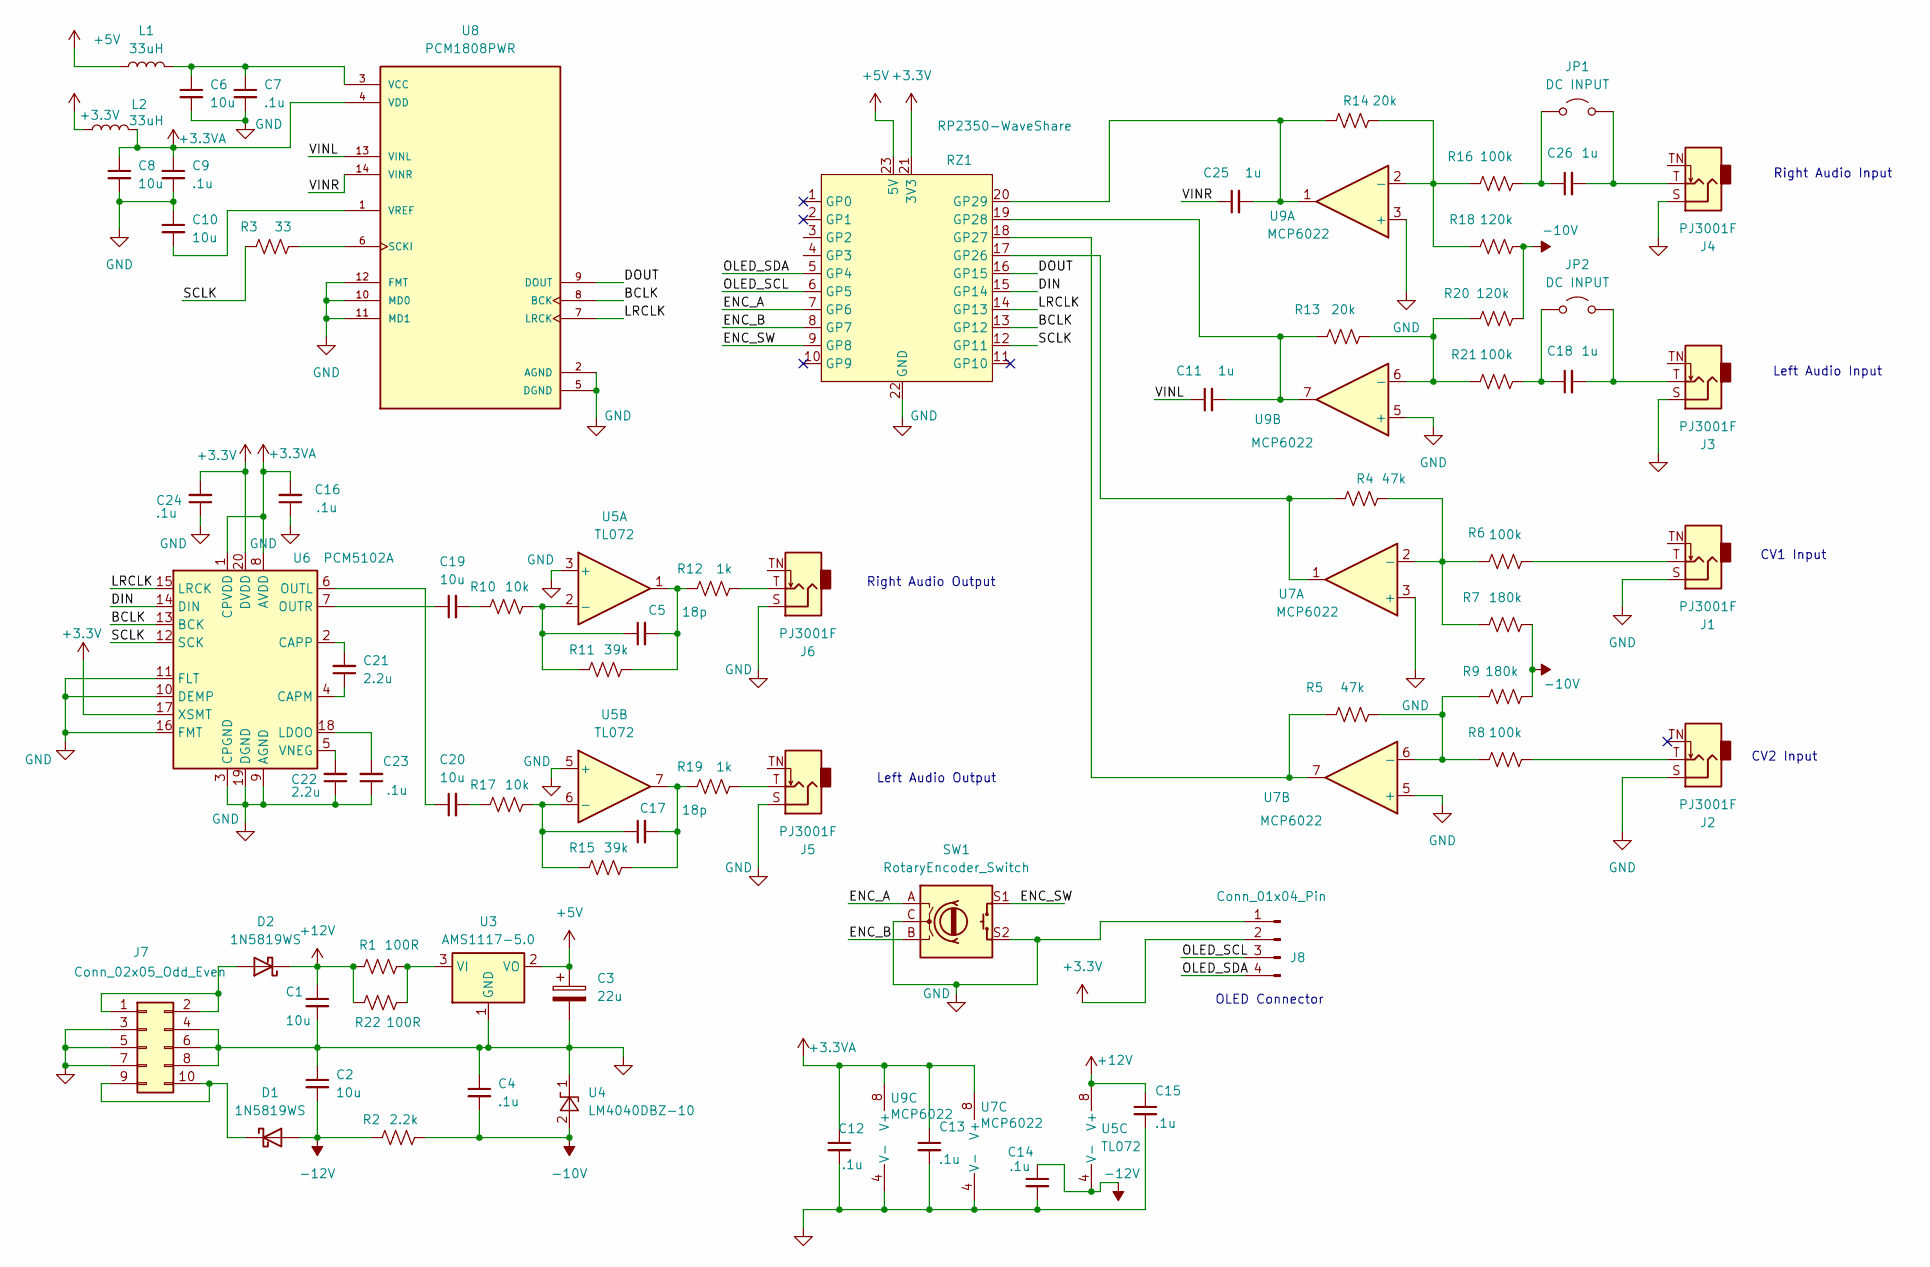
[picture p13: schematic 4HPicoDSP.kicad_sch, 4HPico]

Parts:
C1, C2, C6, C8, C10, C19, C20: 10u; C_0603_1608Metric_Pad1.08x0.95mm_HandSolder
C3: 22u; CP_Elec_5x5.9
C4, C7, C9, C12, C13, C14, C15, C16, C23, C24: .1u; C_0603_1608Metric_Pad1.08x0.95mm_HandSolder
C5, C17: 18p; C_0603_1608Metric_Pad1.08x0.95mm_HandSolder
C11, C18, C25, C26: 1u; C_0603_1608Metric_Pad1.08x0.95mm_HandSolder
C21, C22: 2.2u; C_0603_1608Metric_Pad1.08x0.95mm_HandSolder
D1, D2: 1N5819WS; D_SOD-123
J1, J2, J3, J4, J5, J6: PJ3001F; AudioJack_3.5mm
J7: Conn_02x05_Odd_Even; PinHeader_2x05_P2.54mm_Vertical
J8: Conn_01x04_Pin; PinHeader_1x04_P2.54mm_Vertical
JP1, JP2: DC INPUT; SolderJumper-2_P1.3mm_Open_RoundedPad1.0x1.5mm
L1, L2: 33uH; L_0603_1608Metric_Pad1.05x0.95mm_HandSolder
R1, R22: 100R; R_1206_3216Metric_Pad1.30x1.75mm_HandSolder
R2: 2.2k; R_0603_1608Metric_Pad0.98x0.95mm_HandSolder
R3: 33; R_0603_1608Metric_Pad0.98x0.95mm_HandSolder
R4, R5: 47k; R_0603_1608Metric_Pad0.98x0.95mm_HandSolder
R6, R8, R16, R21: 100k; R_0603_1608Metric_Pad0.98x0.95mm_HandSolder
R7, R9: 180k; R_0603_1608Metric_Pad0.98x0.95mm_HandSolder
R10, R17: 10k; R_0603_1608Metric_Pad0.98x0.95mm_HandSolder
R11, R15: 39k; R_0603_1608Metric_Pad0.98x0.95mm_HandSolder
R12, R19: 1k; R_0603_1608Metric_Pad0.98x0.95mm_HandSolder
R13, R14: 20k; R_0603_1608Metric_Pad0.98x0.95mm_HandSolder
R18, R20: 120k; R_0603_1608Metric_Pad0.98x0.95mm_HandSolder
RZ1: RP2350-WaveShare; RP2350-Waveshare
SW1: RotaryEncoder_Switch; RotaryEncoder_Alps_EC11E-Switch_Vertical_H20mm_topsolder
U3: AMS1117-5.0; SOT-223-3_TabPin2
U4: LM4040DBZ-10; SOT-23
U5: TL072; SOIC-8_3.9x4.9mm_P1.27mm
U6: PCM5102A; TSSOP-20_4.4x6.5mm_P0.65mm
U7, U9: MCP6022; SOIC-8_3.9x4.9mm_P1.27mm
U8: PCM1808PWR; TSSOP-14_4.4x5mm_P0.65mm; PARTREV B; DigiKey_Part_Number 296-26307-1-ND

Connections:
+3.3V: C24.2, J8.2, L2.1, RZ1.21 (3V3), U6.17 (XSMT), U6.20 (DVDD)
+3.3VA: C8.1, C9.1, C12.1, C13.1, C16.2, L2.2, U6.1 (CPVDD), U6.8 (AVDD), U7.8 (V+), U8.4 (VDD), U9.8 (V+)
+5V: C3.1, L1.1, RZ1.23 (5V), U3.2 (VO)
+12V: C1.1, C15.1, D2.1 (K), R1.1, R22.1, U5.8 (V+)
-10V: C4.2, R2.2, R7.2, R9.2, R18.2, R20.2, U4.2 (A)
-12V: C2.2, C14.1, D1.2 (A), R2.1, U5.4 (V-)
/BCLK: RZ1.13 (GP12), U6.13 (BCK), U8.8 (BCK)
/DIN: RZ1.15 (GP14), U6.14 (DIN)
/DOUT: RZ1.16 (GP15), U8.9 (DOUT)
/ENC_A: RZ1.7 (GP6), SW1.A
/ENC_B: RZ1.8 (GP7), SW1.B
/ENC_SW: RZ1.9 (GP8), SW1.S1
/LRCLK: RZ1.14 (GP13), U6.15 (LRCK), U8.7 (LRCK)
/OLED_SCL: J8.3, RZ1.6 (GP5)
/OLED_SDA: J8.4, RZ1.5 (GP4)
/SCLK: R3.1, RZ1.12 (GP11), U6.12 (SCK)
/VINL: C11.1, U8.13 (VINL)
/VINR: C25.1, U8.14 (VINR)
GND: C1.2, C2.1, C3.2, C4.1, C6.2, C7.2, C8.2, C9.2, C10.1, C12.2, C13.2, C14.2, C15.2, C16.1, C22.1, C23.1, C24.1, J1.S, J2.S, J3.S, J4.S, J5.S, J6.S, J7.3, J7.4, J7.5, J7.6, J7.7, J7.8, J8.1, RZ1.22 (GND), SW1.C, SW1.S2, U3.1 (GND), U4.1 (K), U5.3 (+), U5.5 (+), U6.3 (CPGND), U6.9 (AGND), U6.10 (DEMP), U6.11 (FLT), U6.16 (FMT), U6.19 (DGND), U7.3 (+), U7.4 (V-), U7.5 (+), U8.2 (AGND), U8.5 (DGND), U8.10 (MD0), U8.11 (MD1), U8.12 (FMT), U9.3 (+), U9.4 (V-), U9.5 (+)
unnamed: C5.2, R11.2, R12.1, U5.1
unnamed: C17.2, R15.2, R19.1, U5.7
unnamed: C19.2, R10.1
unnamed: C20.2, R17.1
unnamed: D1.1 (K), J7.9, J7.10
unnamed: D2.2 (A), J7.1, J7.2
unnamed: J1.T, R6.2
unnamed: J2.T, R8.2
unnamed: J5.T, R19.2
unnamed: J6.T, R12.2
unnamed: C26.1, JP1.1 (A), R16.2
unnamed: C26.2, J4.T, JP1.2 (B)
unnamed: C18.1, JP2.1 (A), R21.2
unnamed: C18.2, J3.T, JP2.2 (B)
unnamed: R4.1, RZ1.17 (GP26), U7.1
unnamed: R5.1, RZ1.18 (GP27), U7.7
unnamed: C11.2, R13.1, RZ1.19 (GP28), U9.7
unnamed: C25.2, R14.1, RZ1.20 (GP29), U9.1
unnamed: R1.2, R22.2, U3.3 (VI)
unnamed: C5.1, R10.2, R11.1, U5.2 (-)
unnamed: C17.1, R15.1, R17.2, U5.6 (-)
unnamed: C21.1, U6.4 (CAPM)
unnamed: C21.2, U6.2 (CAPP)
unnamed: C23.2, U6.18 (LDOO)
unnamed: C20.1, U6.6 (OUTL)
unnamed: C19.1, U6.7 (OUTR)
unnamed: C22.2, U6.5 (VNEG)
unnamed: R4.2, R6.1, R7.1, U7.2 (-)
unnamed: R5.2, R8.1, R9.1, U7.6 (-)
unnamed: R3.2, U8.6 (SCKI)
unnamed: C6.1, C7.1, L1.2, U8.3 (VCC)
unnamed: C10.2, U8.1 (VREF)
unnamed: R14.2, R16.1, R18.1, U9.2 (-)
unnamed: R13.2, R20.1, R21.1, U9.6 (-)

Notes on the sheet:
CV2 Input
Left Audio Output
Left Audio Input
CV1 Input
OLED Connector
Right Audio Input
Right Audio Output

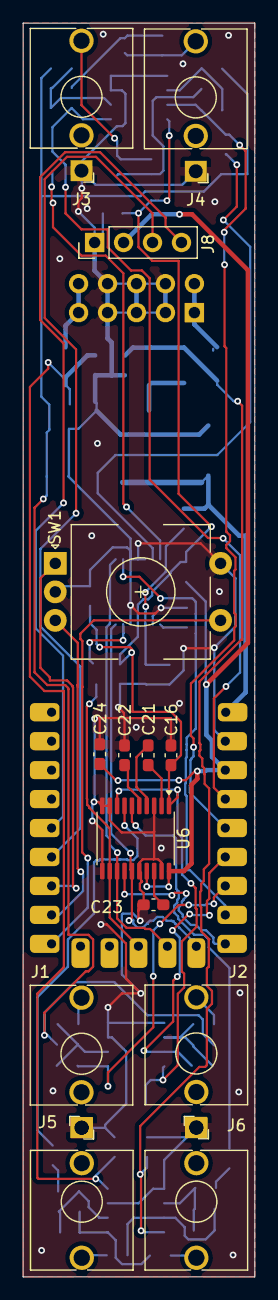
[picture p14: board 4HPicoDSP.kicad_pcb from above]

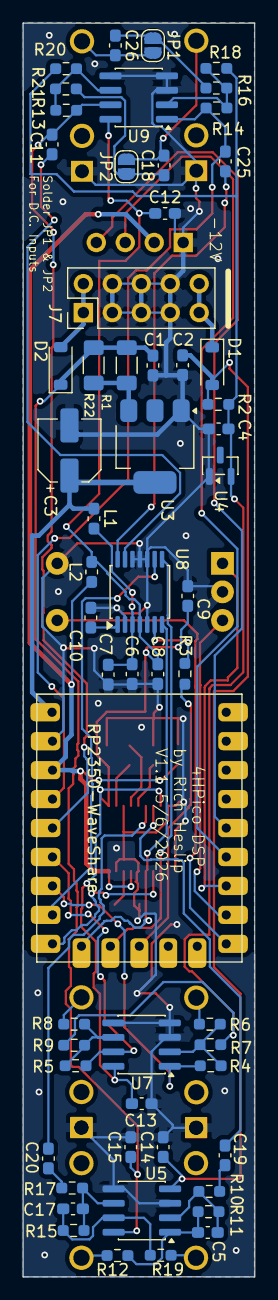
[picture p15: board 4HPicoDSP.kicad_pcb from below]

Board: 2 copper layers, 20.3 x 110.0 mm, 71 parts (57 on the bottom side), 53 nets.

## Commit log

2025-12-19 Updated BOMs, added images
    added more details in BOM and pics of boards
    [2HPico Panel.stl, Pico2HP BOM.xlsx, Pico2HP Controls BOM.xlsx]
2026-01-28 Added 2HPico DSP version and FR4 front panel designs
    New 2HPico DSP board (called 2HPico audio in the archive). Added FR4 front panel as an alternative to the 3D printed panel
    [2HPico Panel.stl, Pico 2HP Front Panel.kicad_pcb, Pico 2HP Front Panel.kicad_sch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]
2026-02-05 Added JLCPCB Assembly files
    Thanks to Blake for the assembly files!
    [BOM-Pico 2HP.csv, BOM-Pico 2HP_Audio.csv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]
2026-02-16 Updated 2HPico DSP schematic, BOM and JLCPCB assy files
    BOM changes as a result of further testing: R1 -> 47 ohms, R10,R17->10k.
    [BOM-Pico 2HP_Audio.csv, Pico 2HP_Audio.kicad_sch, Pico 2HP_Audio_BOM.xlsx]
2026-04-13 Added 4HPico design files
    4HPico is an expanded version of the 2HPico DSP.
    [4HPico.kicad_pcb, 4HPico.kicad_sch, bom.csv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]
2026-05-06 Updated to V1.1
    Connected middle and bottom GND planes. Added panel .stl file for 3D printing.
    [2HPico Panel.stl, 4HPico Panel.stl, 4HPicoDSP.kicad_pcb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]
2026-05-07 Updated 4HPico BOM
    4HPico BOM update, added PDF schematic
    [4HPicoDSPbom.xlsx, bom.xlsx]
